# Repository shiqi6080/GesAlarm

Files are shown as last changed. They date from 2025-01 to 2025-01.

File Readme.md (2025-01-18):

# 基于端侧动作识别的强制唤醒闹钟
本项目立足于生活实际问题进行设计，旨在制作一款通过完成相应动作任务关闭的强制唤醒闹钟，帮助用户迅速清醒。其中，动作识别功能由卷积神经网络完成，利用高效的Edge - AI框架完成了其在STM32上的部署，实现端侧推理。此外，闹钟还具备蓝牙功能，可拓展性较高。

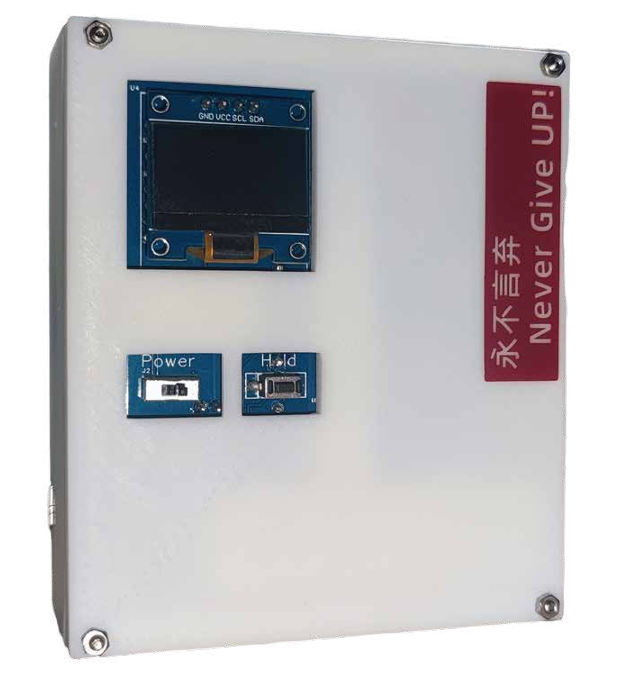
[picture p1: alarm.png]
效果图


## 鸣谢
- 本项目受开源项目[STM32_CyberryPotter_ElectromagicWand_Basic_Project](https://github.com/Hillplain/STM32_CyberryPotter_ElectromagicWand_Basic_Project)启发，并基于其与开源项目[NNOM](https://github.com/majianjia/nnom)开发，感谢相关开发者做出的贡献。
- 本项目仅用于学习交流等非商业用途，如有侵权，立刻删除。

## 设计背景
- 你是否有熬夜或赖床的习惯？是否有因下意识关闭闹钟而迟到的经历？是否会被室友反反复复的闹钟吵醒？
- 是否期望有一款闹钟，能使你不再被赖床和拖延困扰，关掉闹钟即可清醒；能让舍友在闹钟响一次之后，就会立刻起床？

## 系统框架
|模式|流程|
| ---- | ---- |
|正常工作模式（单片机）|显示屏、加速度计、蜂鸣器、滤波处理、蓝牙、时钟协同工作|
|数据采集与训练模式（PC）|自建数据集、模型训练、训练好的模型、分类效果测试，最终将训练好的模型部署到单片机|

## 功能介绍
1. **设置闹钟时间**：通过蓝牙向设备发送消息设置。
2. **响铃暂停操作**：闹钟响铃时，单击Hold键，响铃暂停。
3. **动作关闭闹钟**：在接下来的3s内根据屏幕提示完成动作。每次随机检验1 - 2组动作，如果顺利完成闹钟将关闭，否则持续响铃。
    >目前支持的动作：
    >水平下移、水平上移、画字母e、画字母b、画字母v

## 产品特点
1. **成本优势**：使用低成本的STM32F103系列芯片即可实现预定效果。
2. **数据自主**：所需数据集规模小，可自主采集，无需额外成本。
3. **拓展性强**：配备蓝牙模块，能够与其他设备通信，具有丰富的拓展可能。

## 如何使用
### 硬件
#### 材料清单
1. STM32F103C8T6单片机
2. 加速度计MPU6050
3. 有源音乐模块
4. 0.96寸OLED显示屏（I2C）
5. 电源管理模块（5V输出）
6. HC-05蓝牙模块（串口通信）
7. 拨动开关、按键、六针脚排母各一个

#### 硬件连接
请根据PCB上的丝印焊接，效果如下：

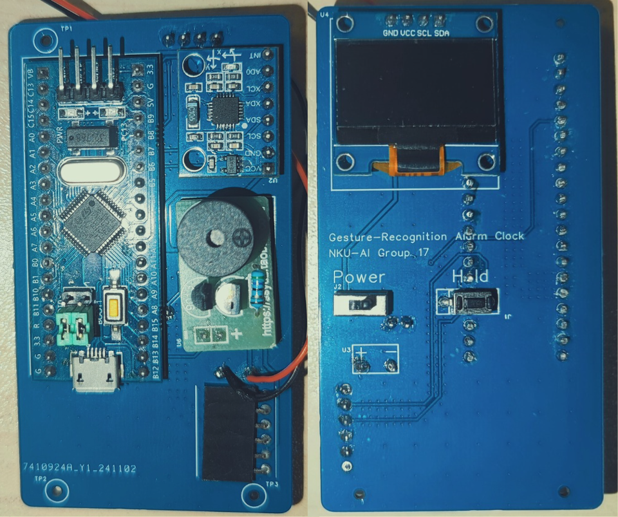
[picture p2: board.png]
焊接效果图

>蓝牙模块插在排母上，电源管理模块未在PCB上画出，需使用导线连接至PCB预留焊盘。

具体连接位置:
>屏幕安装位置：SCL--PB10; SDA--PB11
串口安装位置：PA9(TX)--RX; PA10(RX)--TX
加速度计安装位置：SCL--PB6; SDA--PB7; INT--PB5
蜂鸣器安装位置：PA7(OD输出)
按键安装位置：PA0--3V3之间

注：5V供电通过最小系统板转换为3V3，为其余模块供电，**仅蓝牙模块为5V直供**。

### 软件
#### 环境配置

- Python环境：

    创建一个Python3.9环境  `conda create --name py39_env python=3.9`并安装项目依赖 `pip install -r requirements.txt`

- Keil环境：
  
  keil版本：keil5
  
  编译器版本：Arm Compiler6.7
  
- 可能存在的问题
    
    编译报错：`C:/Users/xxx/AppData/Local/arm/packs/Keil/STM32F1xx_DFP/2.4.1/Device/StdPeriph_Driver/src/misc.c:131:11: error: no member named 'IP' in 'NVIC_Type'`

    这是项目使用到的STM32F1XX_DFP2.4.1版本库存在的一个问题，这个有问题的文件安装在以下目录，默认是只读的，请在这个目录下将其只读选项取消勾选
    `C:/Users/xxx/AppData/Local/arm/packs/Keil/STM32F1xx_DFP/2.4.1/Device/StdPeriph_Driver/src/misc.c`
        
    （AppData文件夹默认是隐藏的，请先设置显示隐藏文件）
        
    请将device库中将misc.c文件里的上述代码（131行）修改为
    `NVIC->IPR[NVIC_InitStruct->NVIC_IRQChannel] = tmppriority`

#### 如何训练

1. 使用[脚本](/Software/CNN/Serial_Read.py)收集数据
   - 首先需要将config.h文件中的`SYSTEM_MODE_DATA_COLLECT`解除注释
   - 完成以上操作后单片机将进入数据打印模式而非推理模式
2. 运行[模型训练](/Software/CNN/CNNTrainRaw.py)脚本
   - 运行训练脚本你将得到一个.h5的模型文件和一个.h的c头文件
   - .h5文件用于在[串口模型测试脚本](/Software/CNN/CNNTestSerialRaw.py)对未量化的模型进行测试
   - .h文件是单片机用于编译模型所需要的文件
3. 打开[Keil工程](/Software/project.uvprojx)编译、烧录
4. 在不改变动作时，无需重复训练，该项目中包含[训练好的模型文件](/Software/CNN/model.h5)和对应的[量化版本](/Software/CNN/weights.h)

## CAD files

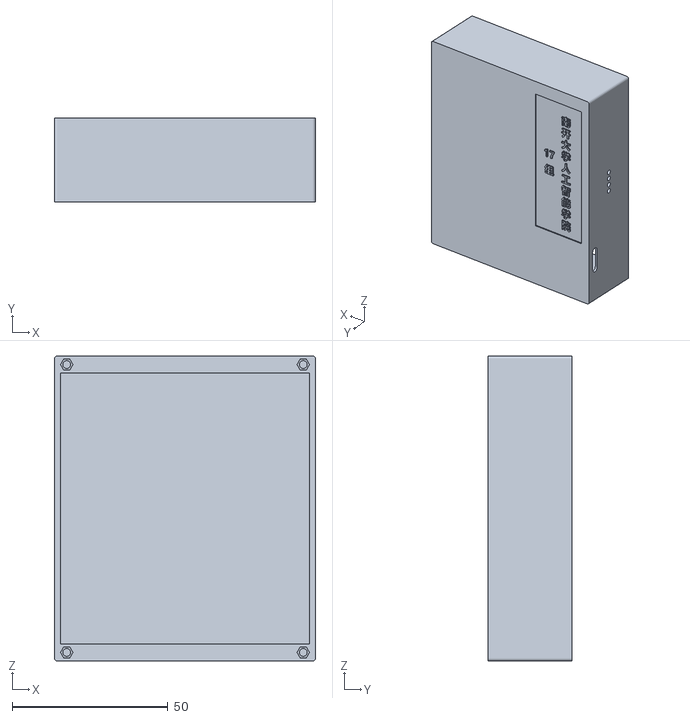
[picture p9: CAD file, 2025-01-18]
Hardware/Shell_b.STL
84.0 x 27.0 x 98.0

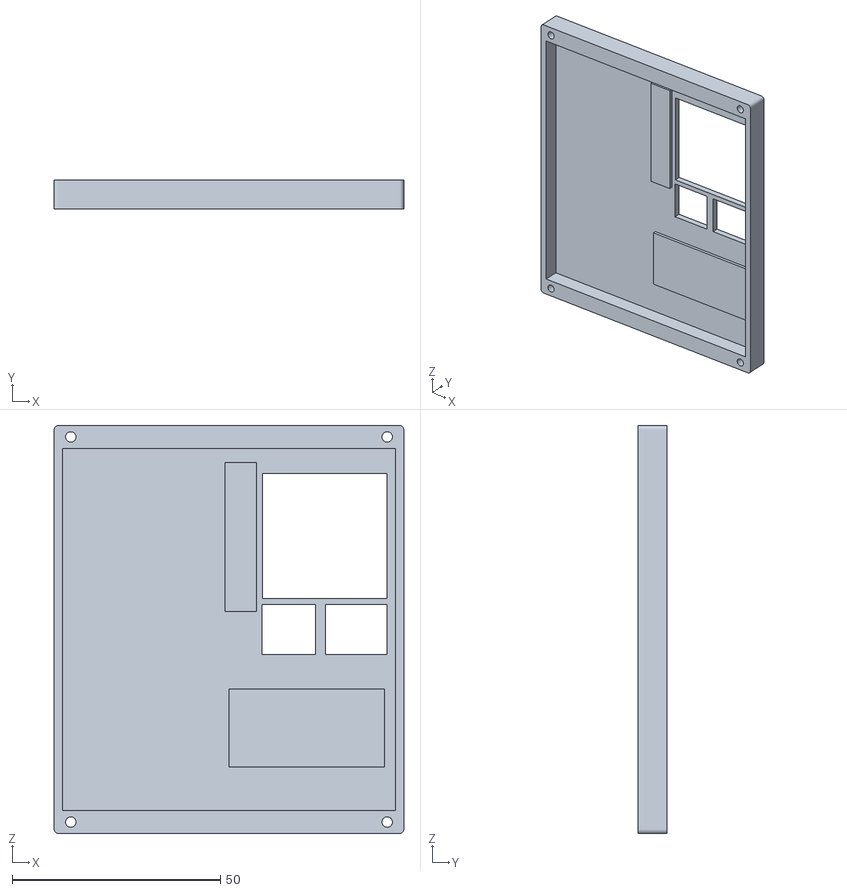
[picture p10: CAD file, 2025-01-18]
Hardware/Shell_a.STL
84.0 x 7.00 x 98.0

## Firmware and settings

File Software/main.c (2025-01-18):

#include "GesAlarm.h"
#include "weights.h"
#include "nnom.h"
#include "alarm.h"


extern Ges_Alarm_Status_Typedef Ges_Alarm_Status;
extern float IMU_Data_mAngle[IMU_SEQUENCE_LENGTH_MAX][3];
extern float IMU_Data_mAcc[IMU_SEQUENCE_LENGTH_MAX][3];
int8_t model_output = -1;
uint8_t screenflag = 1;
#define SCALE (pow(2,INPUT_1_OUTPUT_DEC))

#ifdef NNOM_USING_STATIC_MEMORY
	uint8_t static_buf[1024 * 8];
#endif //NNOM_USING_STATIC_MEMORY

void model_feed_data(void)
{
	const double scale = SCALE;
	uint16_t i = 0;
	for(i = 0; i < IMU_SEQUENCE_LENGTH_MAX;i++){
		nnom_input_data[i*3] = (int8_t)round(IMU_Data_mAcc[i][0] * scale);
		nnom_input_data[i*3+1] = (int8_t)round(IMU_Data_mAcc[i][1] * scale);
		nnom_input_data[i*3+2] = (int8_t)round(IMU_Data_mAcc[i][2] * scale);
	}
}

int8_t model_get_output(void)
{
	uint8_t i = 0;
	int8_t max_output = -128;
	int8_t ret = 0;
	for(i = 0; i < 5;i++){
		printf("Output[%d] = %.2f %%\n",i,(nnom_output_data[i] / 127.0)*100);
		if(nnom_output_data[i] >= max_output){
			max_output = nnom_output_data[i] ;
			ret = i;
		}
	}
	if(max_output >= OUPUT_THRESHOLD){
		ret = ret;
	}
	else{
		ret = -1;
	}
	printf("\n");
	return ret;
}




void motion_check(nnom_model_t* model){
	int8_t motion = MyRTC_Time[4]%5;
	Delay_ms(50);
	OLED_Show(motion+2);
	while(Is_Alarm_On==1){
		if(Ges_Alarm_Status.Button_Status == BUTTON_HOLD && Ges_Alarm_Status.IMU_Status == IMU_Idle){
			IMU_Sample_Start();	 
			//printf("HOLD\n");
			GPIO_WriteBit(GPIOA,GPIO_Pin_7,Bit_SET);
		}
		else if(Ges_Alarm_Status.Button_Status != BUTTON_IDLE){
			Ges_Alarm_Status.Button_Status = BUTTON_IDLE;
		}

		if(Ges_Alarm_Status.IMU_Status == IMU_Sampled){
			#ifdef SYSTEM_MODE_DATA_COLLECT
			Delay_ms(200);
			IMU_Data_Print();
			Ges_Alarm_Status.IMU_Status = IMU_Idle;
			return;
			#endif //SYSTEM_MODE_DATA_COLLECT
			
			#ifndef SYSTEM_MODE_DATA_COLLECT
			model_feed_data();
			model_run(model);
			model_output = model_get_output();
			printf("%d",model_output);
			//Model_LED(model_output);
			#endif //SYSTEM_MODE_DATA_COLLECT
			Ges_Alarm_Status.IMU_Status = IMU_Idle;
			EXTI_Restore();
		}
		if(Ges_Alarm_Status.IMU_Status == IMU_Idle){
			if(model_output == motion){
				Is_Alarm_On = 2;
			}
			else{
				GPIO_WriteBit(GPIOA,GPIO_Pin_7,Bit_RESET);
			}
		}
	}
	OLED_Clear();
	MyRTC_ReadTime();
	int8_t motion1 = MyRTC_Time[5]%5;
	if (motion == motion1){
		motion = (motion+1)%5;
	}
	else{
		motion = motion1;
	}
	Delay_ms(50);
	OLED_Show(motion+2);
	model_output = -1;
	while(Is_Alarm_On==2){
		if(Ges_Alarm_Status.Button_Status == BUTTON_HOLD && Ges_Alarm_Status.IMU_Status == IMU_Idle){
			IMU_Sample_Start();	 
			printf("HOLD\n");
			GPIO_WriteBit(GPIOA,GPIO_Pin_7,Bit_SET);
		}
		else if(Ges_Alarm_Status.Button_Status != BUTTON_IDLE){
			Ges_Alarm_Status.Button_Status = BUTTON_IDLE;
		}

		if(Ges_Alarm_Status.IMU_Status == IMU_Sampled){
			#ifdef SYSTEM_MODE_DATA_COLLECT
			Delay_ms(200);
			IMU_Data_Print();
			#endif //SYSTEM_MODE_DATA_COLLECT
			
			#ifndef SYSTEM_MODE_DATA_COLLECT
			model_feed_data();
			model_run(model);
			model_output = model_get_output();
			printf("%d",model_output);
			//Model_LED(model_output);
			#endif //SYSTEM_MODE_DATA_COLLECT
			Ges_Alarm_Status.IMU_Status = IMU_Idle;
			EXTI_Restore();
		}
		if(Ges_Alarm_Status.IMU_Status == IMU_Idle){
			if(model_output == motion){
				Is_Alarm_On = 0;
			}
			else{
				GPIO_WriteBit(GPIOA,GPIO_Pin_7,Bit_RESET);
			}
		}
	}
	OLED_Clear();
	GPIO_WriteBit(GPIOA,GPIO_Pin_7,Bit_SET);
	Delay_ms(50);
	OLED_Show(7);
	Delay_s(2);
	OLED_Clear();
	screenflag = 0;
	model_output = -1;
}

int  main(void)
{       
    System_Init();
	Serial_Cmd_Init();
    printf("Hello!\n");
    GPIO_WriteBit(GPIOA,GPIO_Pin_7,Bit_SET);
	#ifdef NNOM_USING_STATIC_MEMORY
		nnom_set_static_buf(static_buf, sizeof(static_buf)); 
	#endif //NNOM_USING_STATIC_MEMORY
	nnom_model_t* model;
	model = nnom_model_create(); 
	
	while(1){
		MyRTC_ReadTime();
		if (MyRTC_Time[3] == Next_Alarm_Time[0] && MyRTC_Time[4] == Next_Alarm_Time[1] && MyRTC_Time[5] == 0){
			Is_Alarm_On = 1;
		}
		
		#ifdef SYSTEM_MODE_DATA_COLLECT
		if(Ges_Alarm_Status.Button_Status == BUTTON_HOLD && Ges_Alarm_Status.IMU_Status == IMU_Idle){
			IMU_Sample_Start();
			GPIO_WriteBit(GPIOA,GPIO_Pin_7,Bit_SET);
		}
		else if(Ges_Alarm_Status.Button_Status != BUTTON_IDLE){
			Ges_Alarm_Status.Button_Status = BUTTON_IDLE;
		}
		if(Ges_Alarm_Status.IMU_Status == IMU_Sampled){
			Delay_ms(200);
			IMU_Data_Print();
			Ges_Alarm_Status.IMU_Status = IMU_Idle;
			EXTI_Restore();
		}
		#endif //SYSTEM_MODE_DATA_COLLECT
		#ifndef SYSTEM_MODE_DATA_COLLECT
		if(Is_Alarm_On == 1){
			OLED_Clear();
			GPIO_WriteBit(GPIOA,GPIO_Pin_7,Bit_RESET);
			motion_check(model);
		}
		#endif //SYSTEM_MODE_DATA_COLLECT
		
		if(Ges_Alarm_Status.Button_Status == BUTTON_HOLD){
			screenflag = 60;
			Ges_Alarm_Status.Button_Status = BUTTON_IDLE;
		}
		else if(Ges_Alarm_Status.Button_Status != BUTTON_IDLE){
			Ges_Alarm_Status.Button_Status = BUTTON_IDLE;
		}
		if(screenflag){
			OLED_Show(1);
			screenflag--;
		}
		else{
			OLED_Clear();
		}

		Delay_ms(500);
	}
}

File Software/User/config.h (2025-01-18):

#ifndef _CONFIG_H_
#define _CONFIG_H_

// This file contains compile-time configurations for Cyberry Potter magical wand internal system.


#include "stm32f10x.h"                  // Device header
#include <stdio.h>
#include <string.h>
#include <stdlib.h>


//Define system configuration
#define SYSTEM_FREQUENCY (72000000)
//#define SYSTEM_MODE_DATA_COLLECT
//#define Sound_OFF

// Define Serial baud rate
#define BAUD_RATE 9600
//#define BAUD_RATE (115200)
//#define BAUD_RATE (921600)

//Define TIM4
#define TIM4_PER_INTERRUPT_MS (1)

//Define BUTTON 
#define BUTTON_IDLE_SHORT_THRESHOLD_MS (5)
#define BUTTON_SHORT_LONG_THRESHOLD_MS (1000)
#define BUTTON_LONG_VERYLONG_THRESHOLD_MS (2500)

//Define some useful constant
#define PI (3.14159265f)

//Define IMU
#define IMU_IS_MPU6050
#define IMU_ACC_MAX 4
#define IMU_GYRO_MAX 500
#define IMU_DATA_PRINT_HEADER "IMU\n"
#define IMU_DEFAULT_HZ  (100)
#define IMU_SAMPLING_TIME_MS (1500)
#define IMU_SAMPLING_TIME_S (1.5)
#define IMU_SEQUENCE_LENGTH_MAX (150)
#define IMU_SAMPLING_DELAY_MS (IMU_SAMPLING_TIME_MS/IMU_SEQUENCE_LENGTH_MAX)
#define IMU_TIME_INTERVAL_S (0.025)
#define IMU_ACC_TRANS_CONSTANT (8192.0)  //+-4g
//+-500 degrees raw value to degree constant is divided by 16.384
//+-500 to radian is divided by (73.537*180/PI) = 4213.359738
#define IMU_GYRO_TRANS_RADIAN_CONSTANT (4213.359738) 

//Define CNN
//The out put of model must bigger than this value unless it will give a unrecognized message
#define OUPUT_THRESHOLD 103 

#endif  //_CONFIG_H_

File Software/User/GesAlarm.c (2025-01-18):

#include "GesAlarm.h"

Ges_Alarm_Status_Typedef Ges_Alarm_Status;

volatile uint16_t time_hold_count_ms = 0;
volatile uint16_t time_release_count_ms = 0;
volatile uint16_t i = 0;

void System_Init(void)
{
        Hardware_Init();
        Ges_Alarm_Status.Button_Click_Count = 0;
        Ges_Alarm_Status.Button_Status = BUTTON_IDLE;
        Ges_Alarm_Status.Serial_Status = Serial_Idle;
	Ges_Alarm_Status.IMU_Status = IMU_Idle;
	Ges_Alarm_Status.LED_Status = LED_ALWAYS_ON;
	Ges_Alarm_Status.System_Mode = SYSTEM_TRANSMIT;
	LED_ON;
}

void Ges_Alarm_System_Status_Update(void)
{
	if(Ges_Alarm_Status.Button_Status == BUTTON_HOLD_VERY_LONG){
	      switch(Ges_Alarm_Status.System_Mode){
		      case SYSTEM_IDLE:
				Ges_Alarm_Status.System_Mode = SYSTEM_TRANSMIT;
				Ges_Alarm_Status.LED_Status = LED_10HZ;
				printf("SYSTEM_TRANSMIT\n");
				break;
		      case SYSTEM_TRANSMIT:
				Ges_Alarm_Status.System_Mode = SYSTEM_RECORD;
				Ges_Alarm_Status.LED_Status = LED_5HZ;
				printf("SYSTEM_RECORD\n");
				break;
		      case SYSTEM_RECORD:
				Ges_Alarm_Status.System_Mode = SYSTEM_IDLE;
				Ges_Alarm_Status.LED_Status = LED_IDLE;
				printf("SYSTEM_IDLE\n");
				break;
	      }  
	      LED_Blink();
	}
	else {
	}
	
}

//IMU read
void EXTI9_5_IRQHandler()
{
	if(EXTI_GetITStatus(EXTI_Line5)==SET){
		IMU_Get_Data(i);
		i++;
		if(i >= IMU_SEQUENCE_LENGTH_MAX){
			Ges_Alarm_Status.IMU_Status = IMU_Sampled;
			i = 0;
			IMU_STOP();
		}	
	EXTI_ClearITPendingBit(EXTI_Line5);	
        }
}

//Button EXTI handler*******************************************************//
void EXTI0_IRQHandler(void)
{
        if(EXTI_GetITStatus(EXTI_Line0)==SET){
		//If previous button status is handled.Then button status must change to IDLE.
		if(Ges_Alarm_Status.Button_Status == BUTTON_IDLE){
			TIMER_FOR_BUTTON_ENABLE;
		}
		else{}//Else do nothing
                EXTI_ClearITPendingBit(EXTI_Line0);
        }
}

//Button status update for a given time
void TIM4_IRQHandler(void)
{
	static uint8_t previous_stuatus = 1;
        if(TIM_GetITStatus(TIM4,TIM_IT_Update) == SET){
		//Read Button status on GPIO for now
		uint8_t current_status = !GPIO_ReadInputDataBit(GPIOA,GPIO_Pin_0);
		
		//If status for now and previous is same,and button is held
		if(previous_stuatus == current_status && current_status == 0){
			
			time_hold_count_ms++;
			//If button status is stable for BUTTON_LONG_VERYLONG_THRESHOLD_MS
			if(time_hold_count_ms >= BUTTON_LONG_VERYLONG_THRESHOLD_MS){
					Ges_Alarm_Status.Button_Status = BUTTON_HOLD_VERY_LONG;
					Ges_Alarm_System_Status_Update();
					Ges_Alarm_Status.Button_Status = BUTTON_IDLE;
					time_release_count_ms = 0;
					time_hold_count_ms = 0;
					TIMER_FOR_BUTTON_DISABLE;
				}
		}
		//If status for now and previous is same,and button is released
		else if(previous_stuatus == current_status && current_status == 1){
			time_release_count_ms++;
			//If button status is stable for BUTTON_IDLE_SHORT_THRESHOLD_MS 
			if(time_release_count_ms >= BUTTON_IDLE_SHORT_THRESHOLD_MS){
				
				//If button status is stable for BUTTON_SHORT_LONG_THRESHOLD_MS
				if(time_hold_count_ms >= BUTTON_SHORT_LONG_THRESHOLD_MS){
					Ges_Alarm_Status.Button_Status = BUTTON_HOLD_LONG;
					//printf("long ");
				}
				//If button status is stable for BUTTON_IDLE_SHORT_THRESHOLD_MS 
				else if(time_hold_count_ms >= BUTTON_IDLE_SHORT_THRESHOLD_MS){
					Ges_Alarm_Status.Button_Status = BUTTON_HOLD;
					//printf("hold ");
				}
				//printf("hold:%d",time_hold_count_ms);
				time_hold_count_ms = 0;
				time_release_count_ms = 0;
				TIMER_FOR_BUTTON_DISABLE;
			}
			else{}	//Else do nothing.
		}
		//If status for now and previous is NOT same.
		else{}
			
		//Status update 
		previous_stuatus = current_status;
		TIM_ClearITPendingBit(TIM4,TIM_IT_Update);
	}
}


void LED_Blink(void)
{
	int i = 0;
        if(Ges_Alarm_Status.LED_Status == LED_5HZ){
		for(i = 0; i < 6; i++){
                LED_OFF;
		Delay_ms(100);
                LED_ON;    
		Delay_ms(100);		
		}
		Ges_Alarm_Status.LED_Status = LED_ALWAYS_ON;
        }
	else if(Ges_Alarm_Status.LED_Status == LED_10HZ){
		for(i = 0; i < 11; i++){
                LED_OFF;
		Delay_ms(50);
                LED_ON;    
		Delay_ms(50);		
		}
		Ges_Alarm_Status.LED_Status = LED_ALWAYS_ON;
        }
	else if (Ges_Alarm_Status.LED_Status == LED_ALWAYS_ON){
		LED_ON;
	}
	else{
		LED_ON;
		Delay_ms(200);
		LED_OFF;
		Delay_ms(500);
		LED_ON;
		Delay_ms(300);
		Ges_Alarm_Status.LED_Status = LED_ALWAYS_ON;
	}
}

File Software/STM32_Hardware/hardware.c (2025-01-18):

#include "hardware.h"

#ifdef IMU_IS_MPU6050 
	#include "MPU6050_Reg.h"
	#include "MPU6050.h"
#endif //IMU_IS_MPU6050

#include "OLED.h"

void IMU_WriteReg(uint8_t RegAddress, uint8_t Data);

void Hardware_Init()
{
//RCC periphral init****************************************************//   
        
        RCC_APB2PeriphClockCmd(RCC_APB2Periph_GPIOB,ENABLE);
	RCC_APB2PeriphClockCmd(RCC_APB2Periph_GPIOA,ENABLE);
        RCC_APB2PeriphClockCmd(RCC_APB2Periph_AFIO,ENABLE);
        RCC_APB2PeriphClockCmd(RCC_APB2Periph_USART1,ENABLE);
        RCC_APB1PeriphClockCmd(RCC_APB1Periph_TIM4,ENABLE);
        
        GPIO_InitTypeDef GPIO_InitStruct;
        TIM_TimeBaseInitTypeDef TIM_TimerBaseInitStruct;
        EXTI_InitTypeDef EXTI_InitStruct;
        NVIC_InitTypeDef NVIC_InitStruct;
	
//Button Init****************************************************//    
        GPIO_InitStruct.GPIO_Pin = GPIO_Pin_0;
        GPIO_InitStruct.GPIO_Mode = GPIO_Mode_IPD;
        GPIO_InitStruct.GPIO_Speed = GPIO_Speed_50MHz;
        GPIO_Init(GPIOA,&GPIO_InitStruct);
        
        EXTI_InitStruct.EXTI_Line = EXTI_Line0;
        EXTI_InitStruct.EXTI_LineCmd = ENABLE;
        EXTI_InitStruct.EXTI_Mode = EXTI_Mode_Interrupt;
        EXTI_InitStruct.EXTI_Trigger = EXTI_Trigger_Rising_Falling;;
        EXTI_Init(&EXTI_InitStruct);
        
        NVIC_InitStruct.NVIC_IRQChannel = EXTI0_IRQn;
        NVIC_InitStruct.NVIC_IRQChannelCmd = ENABLE;
        NVIC_InitStruct.NVIC_IRQChannelPreemptionPriority = 3;
        NVIC_InitStruct.NVIC_IRQChannelSubPriority = 3;
        NVIC_Init(&NVIC_InitStruct);
//TIM4 Init******************************************************//          
        TIM_TimerBaseInitStruct.TIM_Prescaler = 3600 - 1;
	TIM_TimerBaseInitStruct.TIM_CounterMode = TIM_CounterMode_Up;
	TIM_TimerBaseInitStruct.TIM_Period = 20 - 1;                   //1ms per interrupt
	TIM_TimerBaseInitStruct.TIM_ClockDivision = TIM_CKD_DIV1;
	TIM_TimeBaseInit(TIM4,&TIM_TimerBaseInitStruct);
        
        TIM_ClearFlag(TIM4,TIM_FLAG_Update);
	TIM_ITConfig(TIM4,TIM_IT_Update,ENABLE);
	
	NVIC_PriorityGroupConfig(NVIC_PriorityGroup_2);
	NVIC_InitStruct.NVIC_IRQChannel = TIM4_IRQn;
	NVIC_InitStruct.NVIC_IRQChannelCmd = ENABLE;
	NVIC_InitStruct.NVIC_IRQChannelPreemptionPriority = 4;
	NVIC_InitStruct.NVIC_IRQChannelSubPriority = 4;
	NVIC_Init(&NVIC_InitStruct);   
        
//USART init*****************************************//
        GPIO_InitStruct.GPIO_Mode = GPIO_Mode_AF_PP;
	GPIO_InitStruct.GPIO_Pin = GPIO_Pin_9;
	GPIO_InitStruct.GPIO_Speed = GPIO_Speed_50MHz;
	GPIO_Init(GPIOA,&GPIO_InitStruct);
	
	GPIO_InitStruct.GPIO_Mode = GPIO_Mode_IPU;
	GPIO_InitStruct.GPIO_Pin = GPIO_Pin_10;
	GPIO_InitStruct.GPIO_Speed = GPIO_Speed_50MHz;
	GPIO_Init(GPIOA,&GPIO_InitStruct);
	
	USART_InitTypeDef USART_InitStructure;
	USART_InitStructure.USART_BaudRate = BAUD_RATE;
	USART_InitStructure.USART_HardwareFlowControl = USART_HardwareFlowControl_None;
	USART_InitStructure.USART_Mode = USART_Mode_Tx | USART_Mode_Rx;
	USART_InitStructure.USART_Parity = USART_Parity_No;
	USART_InitStructure.USART_StopBits = USART_StopBits_1;
	USART_InitStructure.USART_WordLength = USART_WordLength_8b;
	USART_Init(USART1,&USART_InitStructure);
	
	USART_ITConfig(USART1,USART_IT_RXNE,ENABLE);
	
	NVIC_PriorityGroupConfig(NVIC_PriorityGroup_2);

	NVIC_InitStruct.NVIC_IRQChannel = USART1_IRQn;
	NVIC_InitStruct.NVIC_IRQChannelCmd = ENABLE;
	NVIC_InitStruct.NVIC_IRQChannelPreemptionPriority = 1;
	NVIC_InitStruct.NVIC_IRQChannelSubPriority = 1;
	NVIC_Init(&NVIC_InitStruct);
	
	USART_Cmd(USART1,ENABLE);
        //printf("Hello!\n");
//LED init*****************************************//   
	#ifndef Sound_OFF
	GPIO_InitStruct.GPIO_Mode = GPIO_Mode_Out_OD;
	GPIO_InitStruct.GPIO_Pin = GPIO_Pin_7;
	GPIO_InitStruct.GPIO_Speed = GPIO_Speed_50MHz;
	GPIO_Init(GPIOA,&GPIO_InitStruct); 
	GPIO_WriteBit(GPIOA,GPIO_Pin_7,Bit_SET);
	#endif
	
 //IMU init*****************************************//    	
	
	#ifdef IMU_IS_MPU6050
	GPIO_InitStruct.GPIO_Mode = GPIO_Mode_IPU;
        GPIO_InitStruct.GPIO_Pin = GPIO_Pin_5;
        GPIO_InitStruct.GPIO_Speed = GPIO_Speed_50MHz;
        GPIO_Init(GPIOB,&GPIO_InitStruct);
	
	GPIO_EXTILineConfig(GPIO_PortSourceGPIOB,GPIO_PinSource5); 
	
	EXTI_InitStruct.EXTI_Line = EXTI_Line5 ;
        EXTI_InitStruct.EXTI_LineCmd = ENABLE;
        EXTI_InitStruct.EXTI_Mode = EXTI_Mode_Interrupt;
        EXTI_InitStruct.EXTI_Trigger = EXTI_Trigger_Falling;
        EXTI_Init(&EXTI_InitStruct);
	
	NVIC_InitStruct.NVIC_IRQChannel = EXTI9_5_IRQn;
        NVIC_InitStruct.NVIC_IRQChannelCmd = ENABLE;
        NVIC_InitStruct.NVIC_IRQChannelPreemptionPriority = 6;
        NVIC_InitStruct.NVIC_IRQChannelSubPriority = 6;
        NVIC_Init(&NVIC_InitStruct);
	
	IMU_STOP();
	MPU6050_Init();
	#endif //IMU_IS_MPU6050	
	
	OLED_Init();
}

int fputc( int ch, FILE *f )
{
        while((USART1->SR & (1 << 7) ) == 0);
        USART1->DR = ch;
	return ch;
}
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
